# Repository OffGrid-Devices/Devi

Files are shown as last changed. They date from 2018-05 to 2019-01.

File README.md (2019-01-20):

# Devi
Arduino-based synthesizer 

[BOM](https://docs.google.com/spreadsheets/d/11OAxCDL9WJjP-PPryWPdmoXp5gGi14y3Fq-VU7GaQAA/edit?usp=sharing)

# Notes for further development

## Synth Variables

- fixedfreq (bool)
- coarse 
- detune 
- freqrange
- freqfixed
- depth 
- waveform
- attack
- decay 
- algorithm 

## Main Functions

- handleNoteOn
- handleNoteOff
- handleCC
- handleProgramChange
- sendNoteOn
- sendNoteOff
- sendCC
- sendProgramChange
- setMIDICH // runs @setup()
- setProgChangeBehavior // runs @setup()
- savePreset
- loadPreset
- initParams
- updateParams // hardware version of handleCC

## Control Modes

### 0 - Volumes & Mod Depths (RGB=OFF)
- knobs => depth 
- buttons do nothing (or may play individual oscillators)
- LED's show which oscillators are carriers

### 1 - Frequency (RGB=PURPLE)
- button + function => select if oscillator as fixed frequency or not (indicate with LED)
- knob => detune/freqfixed
- button + knob => coarse/freqrange

### 2 - Envelopes (RGB=BLUE)
- button + knob => attack
- knob => decay

### 3 - Waveform (RGB=WHITE)
- knob => waveform  
- buttons + knob6 => set several 
- function + knob => set all

### 4 - Load Preset (RGB=GREEN)
(leds indicate which preset is loaded using a binary representation)
### 5 - Save Preset (RGB=RED)

## FM Algorithms

### 0: six-voice polyphony, single oscillator
(1)|(2)|(3)|(4)|(5)|(6) 

### 1: three-voice polyphony, dual oscillator
(1)+(2)|(3)+(4)|(5)+(6)

### 2: two-voice polyphony, triple oscillator
(1)+(2)+(3)|(4)+(5)+(6)

### 3: three-voice polyphony, FM 2-operators
(2) | (4) | (6)
 |  |  |  |  |
(1) | (3) | (5)

### 4: two-voice polyphony, FM 3-operators
    (2) |     (6)
     |  |      | 
(1)+(3) | (4)+(5)

### 5: two-voice polyphony, FM 3-operators
  (3)   |   (6)
  / \   |   / \
(1)+(2) | (4)+(5)

### 6: two-voice polyphony, FM 3-operators
(2)+(3) | (5)+(6) 
  \ /   |   \ / 
  (1)   |   (4)

### 7: two-voice polyphony, FM 3-operators
(3) | (6)
 |  |  |
(2) | (5)
 |  |  |
(1) | (4)

### 8: monophonic, FM 6-operators
(3) (6)
 |   |
(2) (5)
 |   |
(1)+(4)

### 9: monophonic, FM 6-operators
  (3)     (6)
  / \     / \
(1)+(2) (4)+(5)

### 10: monophonic, FM 6-operators (needs experimentation...is it worth it have 6 stacked oscils when it is possible to change the waveform?)
    (6)             (6)
     |               |
    (5)             (5)
     |       OR      |
(2) (4)             (4)
 |   |               |
(1)+(3)             (3)
                     |
                    (2)
                     |
                    (1) 

### 11: super monophonic, six oscillators
(1)+(2)+(3)+(4)+(5)+(6)

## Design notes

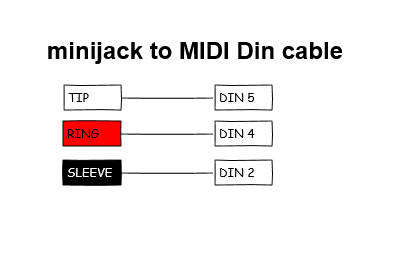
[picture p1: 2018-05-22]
schematics/MIDI minijack cables/MIDI to minijack.png

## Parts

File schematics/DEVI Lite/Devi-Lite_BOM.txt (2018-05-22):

Partlist exported from C:/Users/tiago/Documents/GitHub/OffGrid-Devices/Devi/schematics/DEVI Lite/Devi_Lite.sch at 22-05-2018 23:34

Qty Value               Device                  Package       Parts                                                                                                                                                                                                                   Description                     
7                       3RP/1610N               3RP/1610N     P1, P2, P3, P4, P5, P6, P8                                                                                                                                                                                              16mm Potentiometer one level    
1                       CK101X12                CK101X12      S1                                                                                                                                                                                                                      ROTARY SWITCH                   
7                       LED3MM                  LED3MM        LED1, LED2, LED3, LED4, LED5, LED6, LED7                                                                                                                                                                                LED                             
38                      PINHD-1X1CB             1X01-CLEANBIG JB1, JB2, JB3, JB4, JB5, JB6, JB7, JB8, JLED1, JLED2, JLED3, JLED4, JLED5, JLED6, JLED7, JLEDB, JLEDG, JLEDR, JP1, JP2, JP3, JP4, JP5, JP6, JP8-2, JP8-3, JS1, JS2, JS3, JS4, JS5, JS6, JS7, JS8, JS9, JS10, JS11, JS12 Pin header 1x1 for 0.1" spacing 
8                       SWITCH_PUSHBUTTONEVQ-PE TACT_PANA-EVQ SW1, SW2, SW3, SW4, SW5, SW6, SW7, SW8                                                                                                                                                                                  Buttons                         
2                       W237-103                W237-103      MIDI_IN, MIDI_OUT                                                                                                                                                                                                       WAGO SCREW CLAMP                
20  1K                  1KOHM-HORIZ-1/4W-5%     AXIAL-0.3     R1, R2, R3, R4, R5, R6, R7, R8, R9, R10, R11, R12, R13, R14, R15, R16, R17, R18, R19, R20                                                                                                                               1kO resistor                    
2   1M                  1KOHM-HORIZ-1/4W-5%     AXIAL-0.3     R21, R22                                                                                                                                                                                                                1kO resistor                    
1   200mA/100V/1V       DIODE-1N4148            DIODE-1N4148  D1                                                                                                                                                                                                                      Diode                           
3   220                 1KOHM-HORIZ-1/4W-5%     AXIAL-0.3     R24, R25, R27                                                                                                                                                                                                           1kO resistor                    
1   3K9                 1KOHM-HORIZ-1/4W-5%     AXIAL-0.3     R23                                                                                                                                                                                                                     1kO resistor                    
1   4.7nF               C-EU050-025X075         C050-025X075  C1                                                                                                                                                                                                                      CAPACITOR, European symbol      
1   4K7                 1KOHM-HORIZ-1/4W-5%     AXIAL-0.3     R26                                                                                                                                                                                                                     1kO resistor                    
1   6N138               6N138                   DIL08         OK1                                                                                                                                                                                                                     MOTOROLA OPTO COUPLER           
1   ARDUINO_MEGA_R3FULL ARDUINO_MEGA_R3FULL     ARDUINO_MEGA  B1                                                                                                                                                                                                                      Arduino Mega R3                 
1   CLEAR               LED-RGB-CCCLEAR         LED-RGB-THRU  RGB                                                                                                                                                                                                                     LED-RGB Common Cathode          
1   MONO_PLUG           MONO_PLUG               TWO_PADS      JA

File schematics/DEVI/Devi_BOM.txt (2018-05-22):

Partlist exported from C:/Users/tiago/Documents/GitHub/OffGrid-Devices/Devi/schematic/Devi_revB.sch at 21-05-2018 18:55

Qty Value               Device                  Package       Parts                                                                                                                                                                                                                                                                                                                           Description                     
8                       3RP/1610N               3RP/1610N     P1, P2, P3, P4, P5, P6, P7, P8                                                                                                                                                                                                                                                                                                  16mm Potentiometer one level    
2                       7SEG-CK                 7SEG-13       DLEFT, DRIGHT                                                                                                                                                                                                                                                                                                                   7-segment DISPLAY               
1                       CK101X12                CK101X12      S1                                                                                                                                                                                                                                                                                                                              ROTARY SWITCH                   
7                       LED3MM                  LED3MM        LED1, LED2, LED3, LED4, LED5, LED6, LED7                                                                                                                                                                                                                                                                                        LED                             
63                      PINHD-1X1CB             1X01-CLEANBIG 3V3, 5V, CD, CLK, CS, DI, DO, GND, JB1, JB2, JB3, JB4, JB5, JB6, JB7, JB8, JLED1, JLED2, JLED3, JLED4, JLED5, JLED6, JLED7, JLEDB, JLEDG, JLEDR, JP1, JP2, JP3, JP4, JP5, JP6, JP7, JP8-2, JP8-3, JS1, JS2, JS3, JS4, JS5, JS6, JS7, JS8, JS9, JS10, JS11, JS12, LA, LB, LC, LD, LE, LF, LG, LP, RA, RB, RC, RD, RE, RF, RG, RP Pin header 1x1 for 0.1" spacing 
8                       SWITCH_PUSHBUTTONEVQ-PE TACT_PANA-EVQ SW1, SW2, SW3, SW4, SW5, SW6, SW7, SW8                                                                                                                                                                                                                                                                                          Buttons                         
2                       W237-103                W237-103      MIDI_IN, MIDI_OUT                                                                                                                                                                                                                                                                                                               WAGO SCREW CLAMP                
20  1K                  1KOHM-HORIZ-1/4W-5%     AXIAL-0.3     R1, R2, R3, R4, R5, R6, R7, R8, R9, R10, R11, R12, R13, R14, R15, R16, R17, R18, R19, R20                                                                                                                                                                                                                                       1kO resistor                    
2   1M                  1KOHM-HORIZ-1/4W-5%     AXIAL-0.3     R21, R22                                                                                                                                                                                                                                                                                                                        1kO resistor                    
1   200mA/100V/1V       DIODE-1N4148            DIODE-1N4148  D1                                                                                                                                                                                                                                                                                                                              Diode                           
3   220                 1KOHM-HORIZ-1/4W-5%     AXIAL-0.3     R24, R25, R27                                                                                                                                                                                                                                                                                                                   1kO resistor                    
1   3K9                 1KOHM-HORIZ-1/4W-5%     AXIAL-0.3     R23                                                                                                                                                                                                                                                                                                                             1kO resistor                    
1   4.7nF               C-EU050-025X075         C050-025X075  C1                                                                                                                                                                                                                                                                                                                              CAPACITOR, European symbol      
1   4K7                 1KOHM-HORIZ-1/4W-5%     AXIAL-0.3     R26                                                                                                                                                                                                                                                                                                                             1kO resistor                    
1   6N138               6N138                   DIL08         OK1                                                                                                                                                                                                                                                                                                                             MOTOROLA OPTO COUPLER           
1   ARDUINO_MEGA_R3FULL ARDUINO_MEGA_R3FULL     ARDUINO_MEGA  B1                                                                                                                                                                                                                                                                                                                              Arduino Mega R3                 
1   CLEAR               LED-RGB-CCCLEAR         LED-RGB-THRU  RGB                                                                                                                                                                                                                                                                                                                             LED-RGB Common Cathode          
1   MONO_PLUG           MONO_PLUG               TWO_PADS      JA

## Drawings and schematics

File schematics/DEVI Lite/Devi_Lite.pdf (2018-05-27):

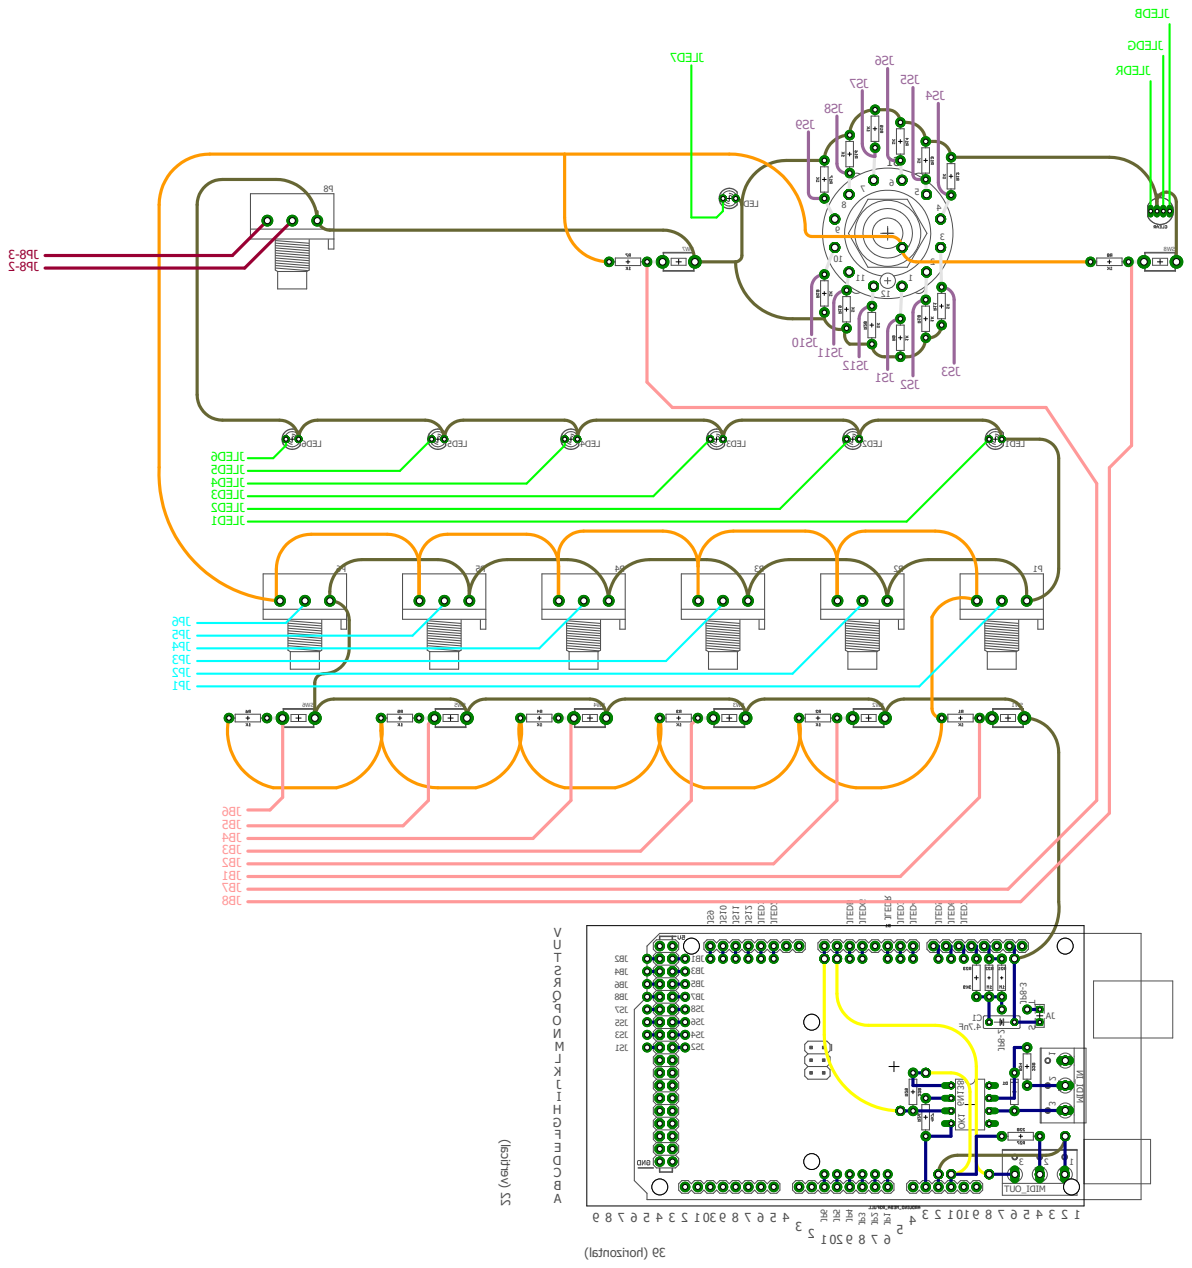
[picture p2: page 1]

Fn7. 4 6N138 1C AJ 2BJ 1BJ 4BJ 3BJ 6BJ 5BJ 8BJ 7BJ JLED1 JLED2 JLED3 JLED4 JLED5 JLED6 JLED7 JLEDB JLEDG JLEDR JP1 JP2 JP3JP4 JP5 JP6 1SJ JS10 JS11 JS12 2SJ 3SJ 4SJ 5SJ 6SJ 7SJ 8SJJS9 6DEL 5DEL 4DEL 3DEL 2DEL 1DEL 7DEL MIDI_IN TUO_I DI M OK1 6P 5P 4P 3P 2P 1P 8P 1S 6 WS 5 WS 4 WS 3 WS 2 WS 1 WS 7 WS 8 WS JP8-3 JP8-2 1 2 3 3 2 1 S T 1 2 34 5 6 7 8 901 11 21 1BJ 2BJ 3BJ 4BJ 5BJ 6BJ 7BJ 8BJ 1PJ 2PJ 3PJ 4PJ 5PJ 6PJ 1DELJ 2DELJ 3DELJ 4DELJ 5DELJ 6DELJ 7DELJ RDELJ GDELJ BDELJ 1SJ 2SJ 3SJ 4SJ 5SJ 6SJ 7SJ 8SJ 9SJ 01SJ11SJ21SJ 3- 8PJ 2- 8PJ )l at nozir oh( 93 22 (vertical) ABCDEFGHIJKLMNOPQRSTUV 3 2 1 01 9 8 7 6 5 4 3 2 1 4 5 1 02 9 8 7 6 2 3 9 8 7 6 5 4 3 2 1 03 9 8 7 6 5 4

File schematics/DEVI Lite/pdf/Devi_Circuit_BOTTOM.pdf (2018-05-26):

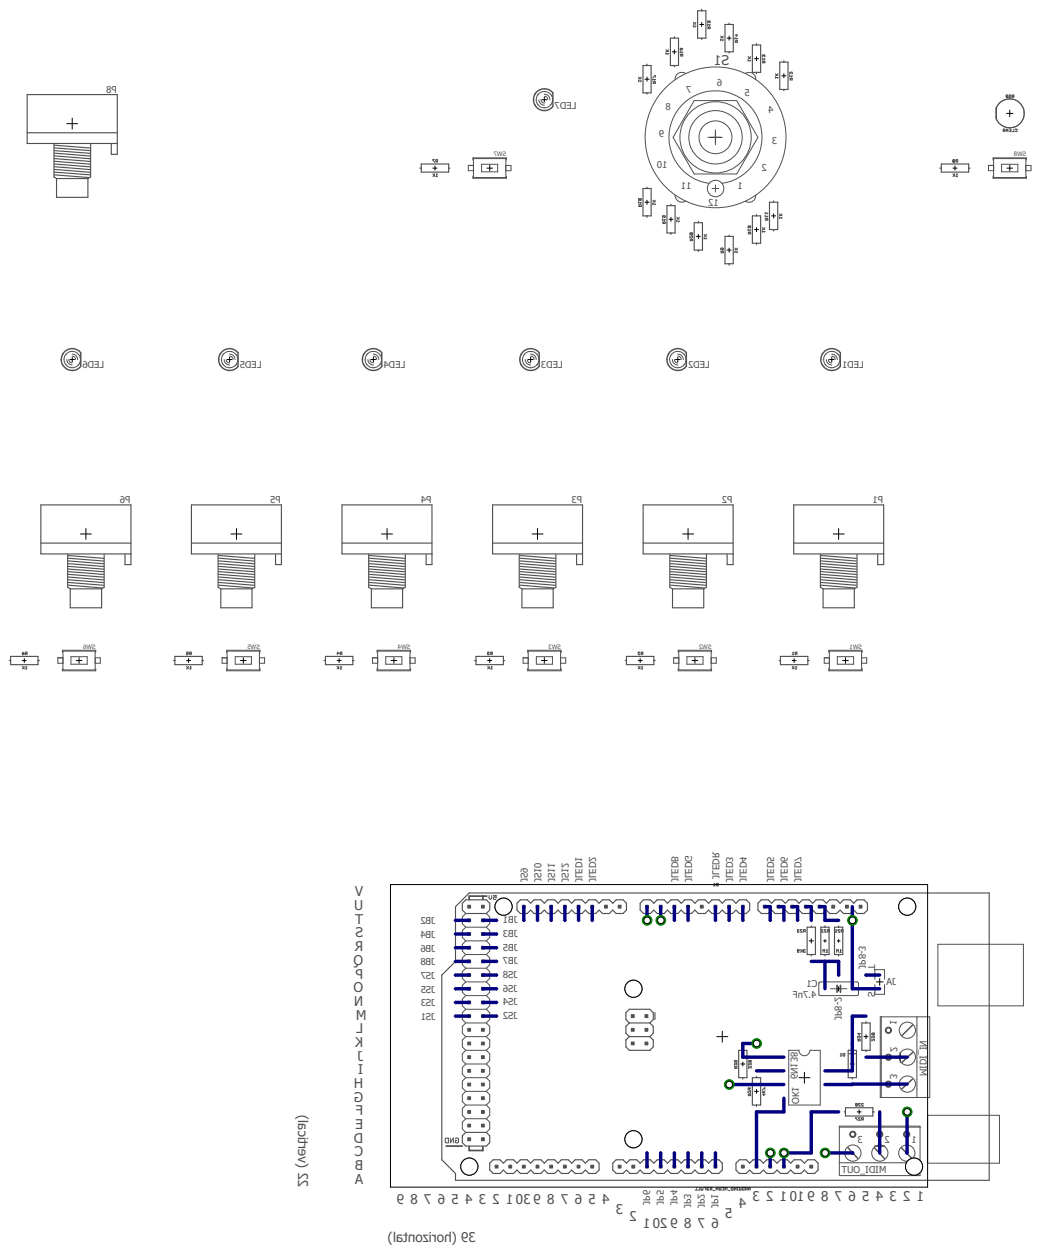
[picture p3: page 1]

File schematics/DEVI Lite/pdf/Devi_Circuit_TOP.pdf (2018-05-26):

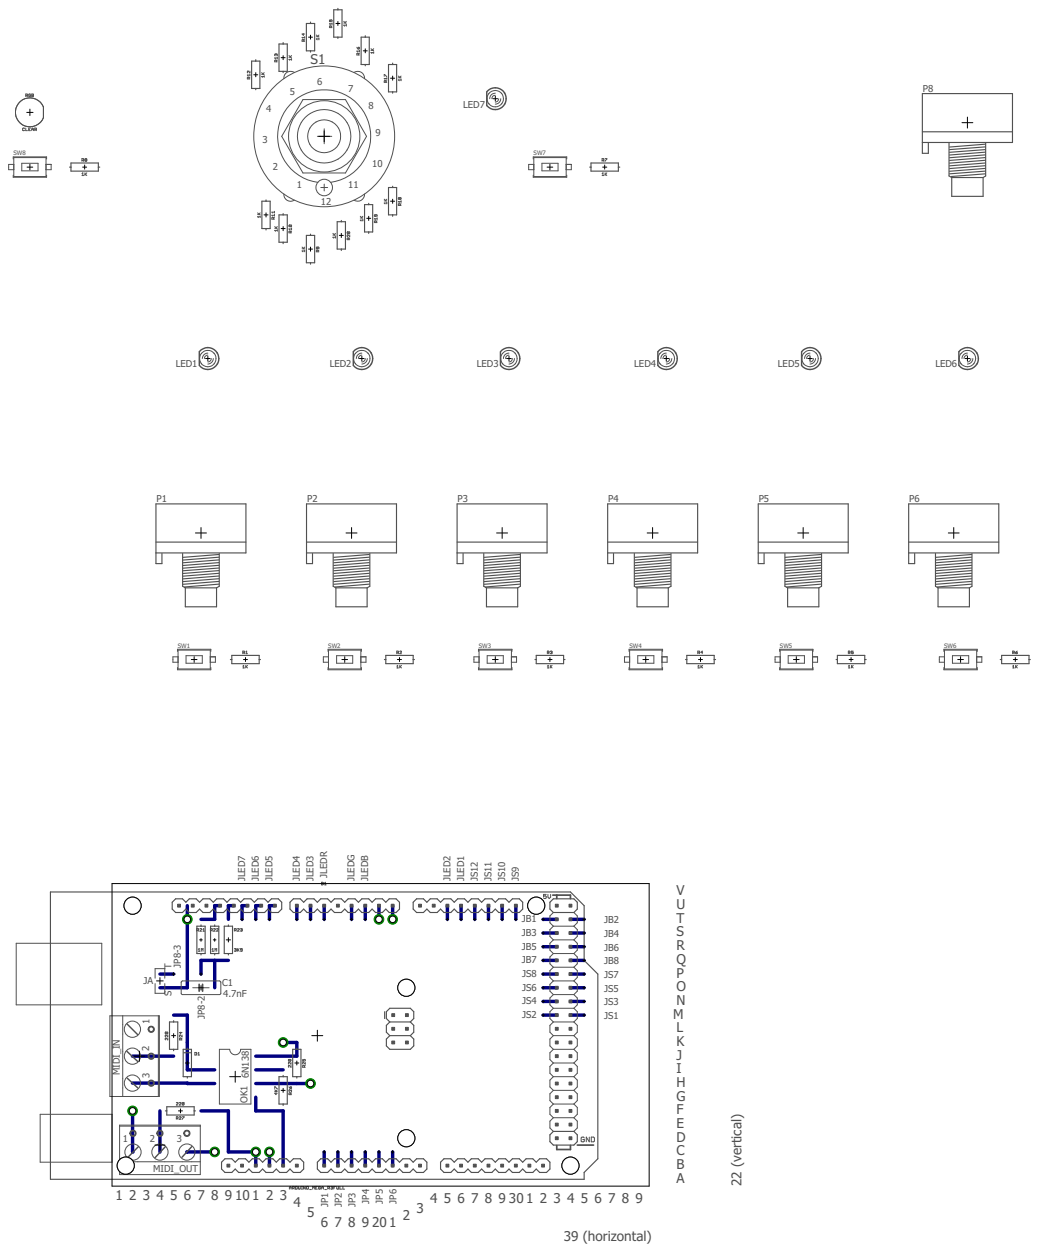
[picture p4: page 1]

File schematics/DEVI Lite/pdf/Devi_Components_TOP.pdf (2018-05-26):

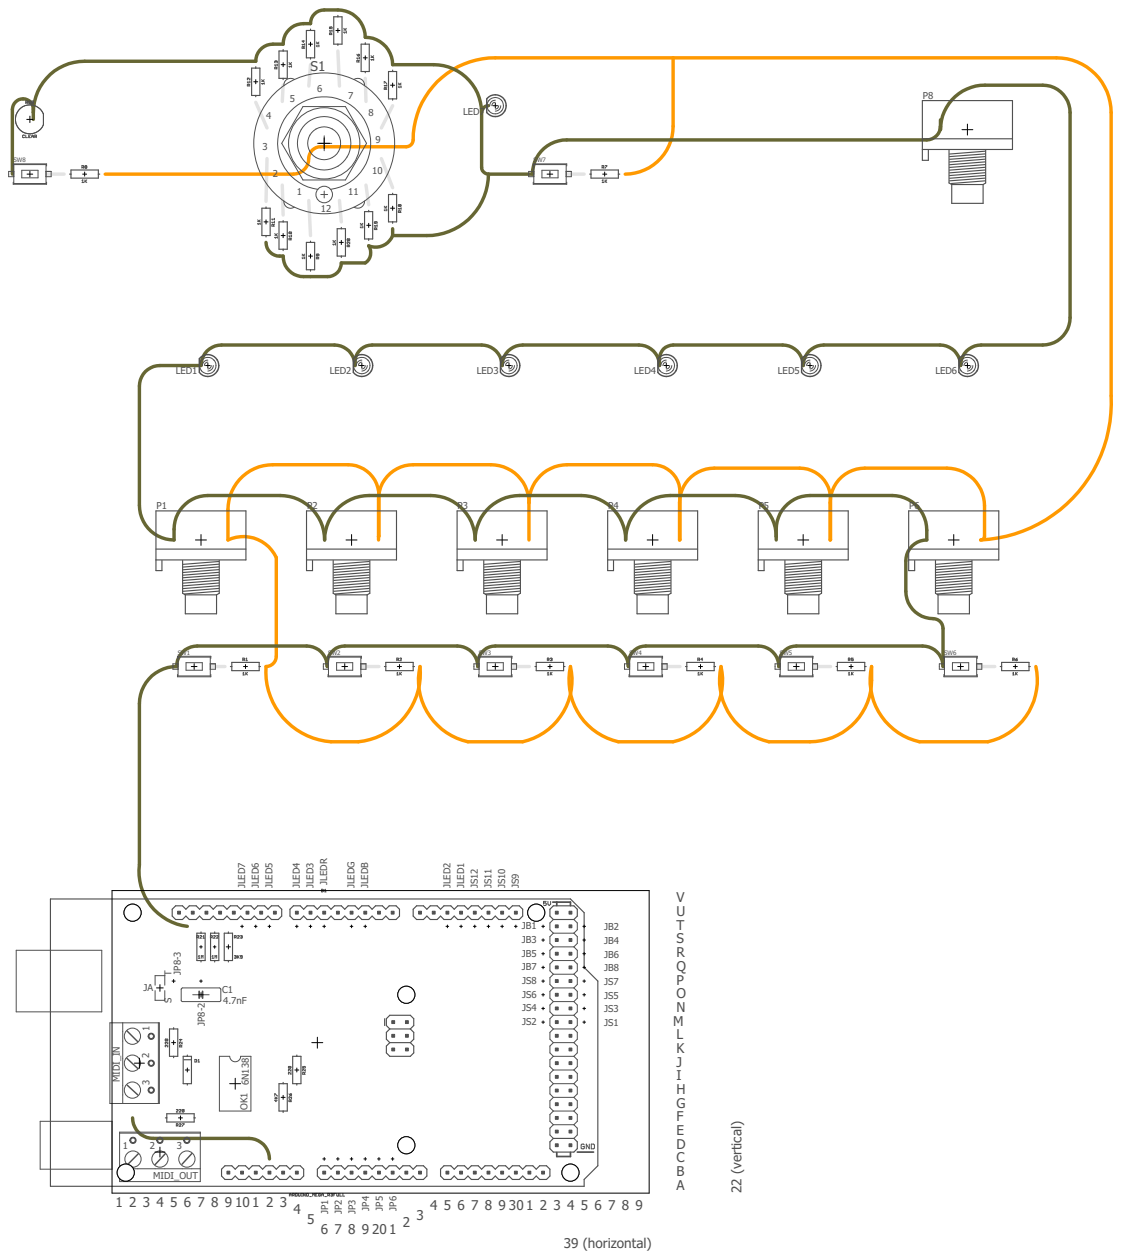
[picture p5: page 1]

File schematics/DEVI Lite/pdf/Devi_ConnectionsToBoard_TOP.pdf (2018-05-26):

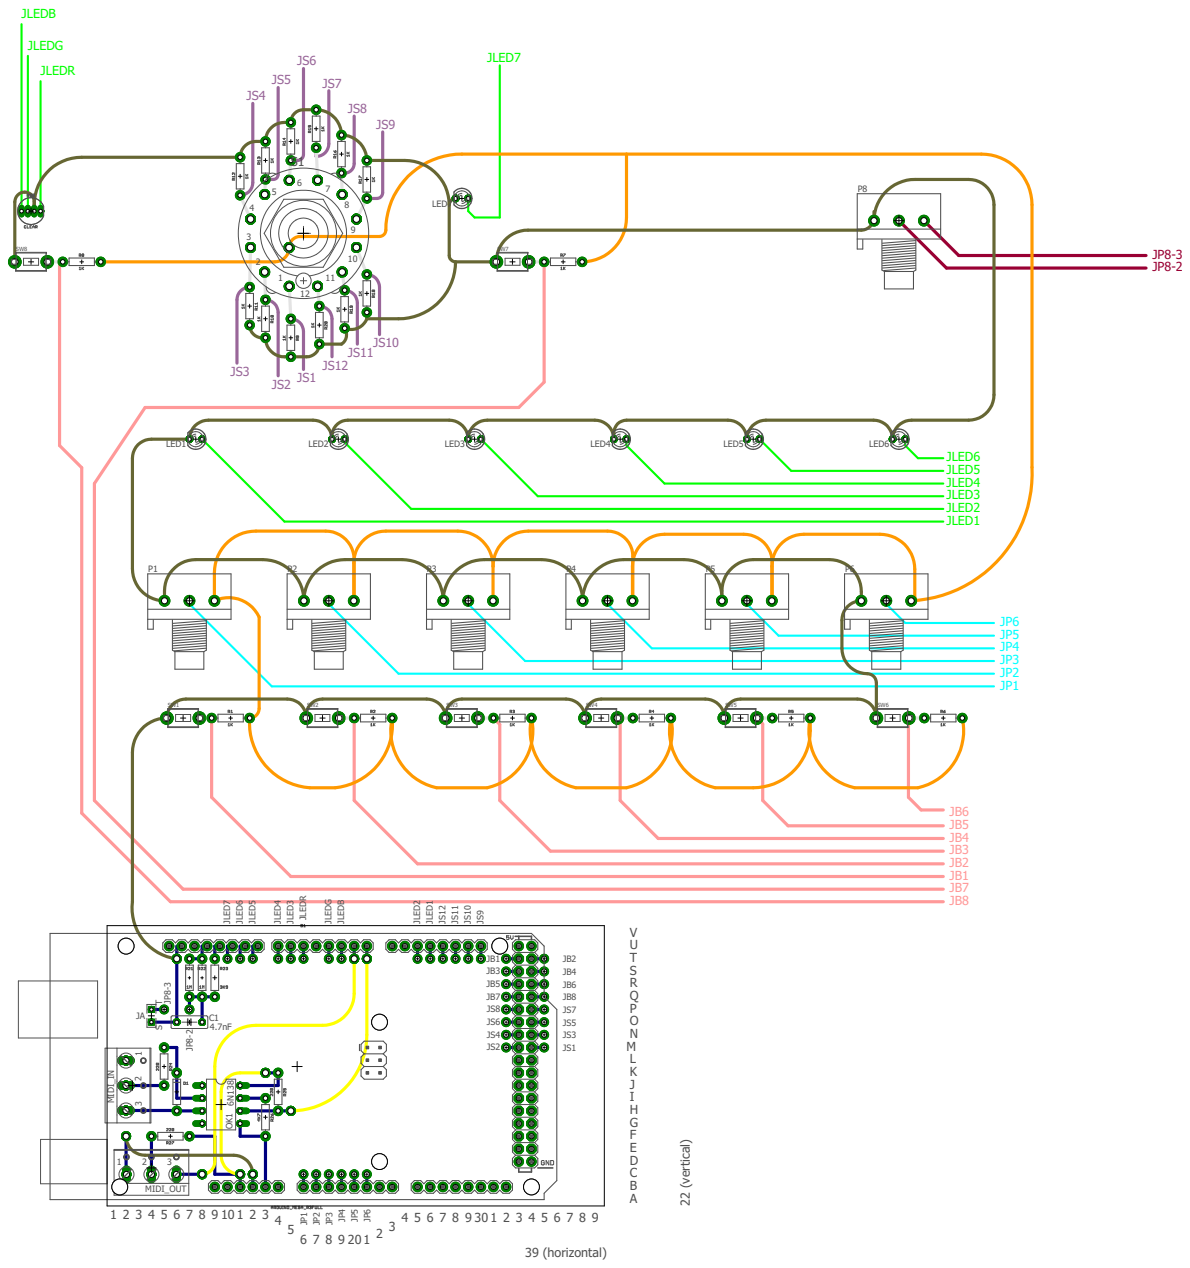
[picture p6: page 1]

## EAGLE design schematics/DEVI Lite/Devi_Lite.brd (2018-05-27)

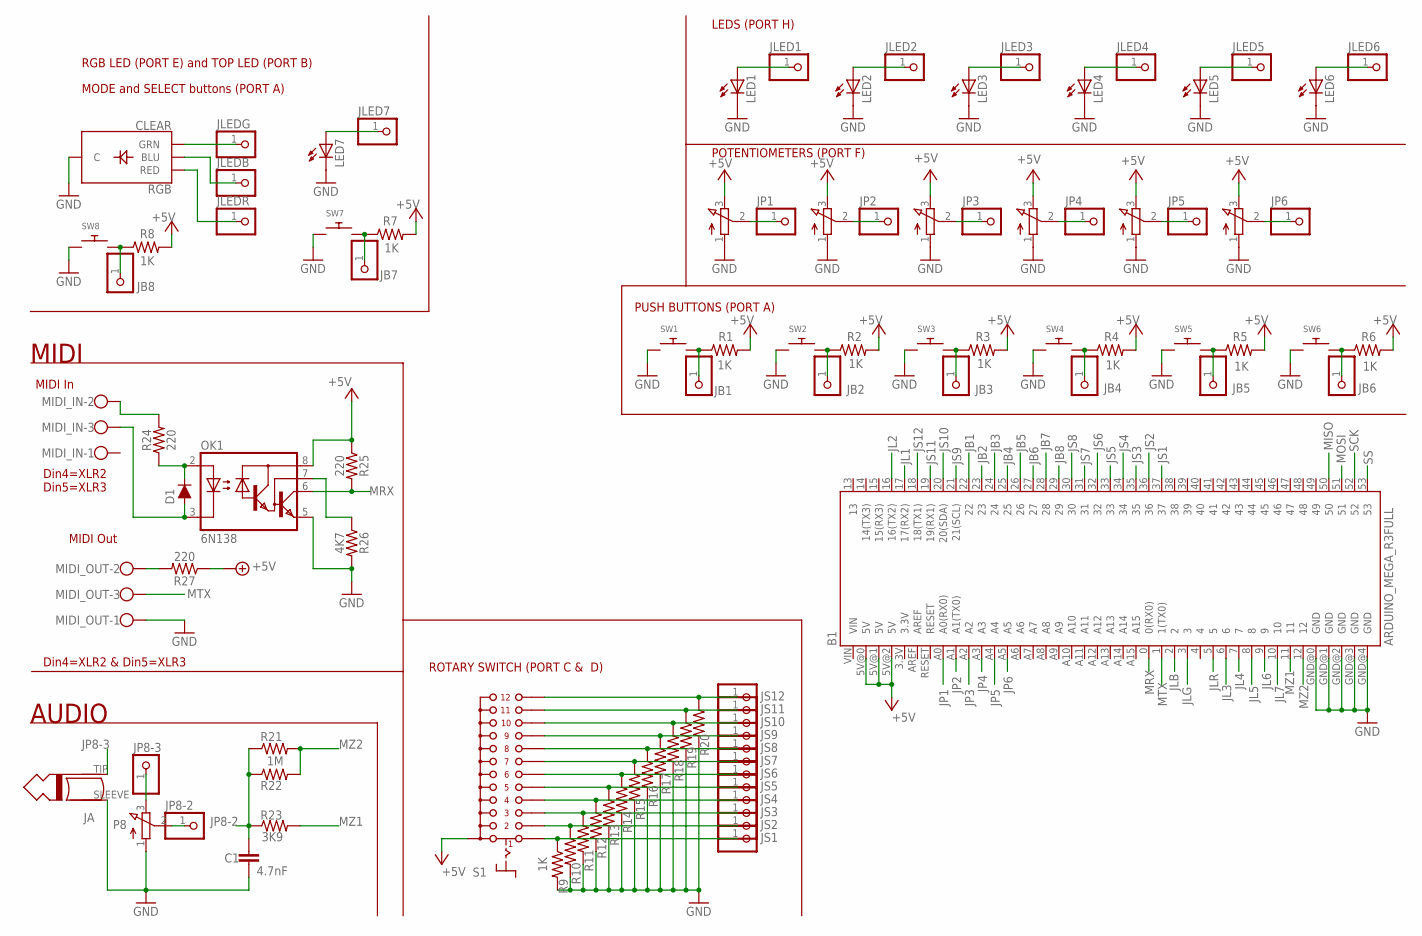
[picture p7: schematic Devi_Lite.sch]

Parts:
B1: ARDUINO_MEGA_R3FULL; ARDUINO_MEGA
C1: 4.7nF; C050-025X075
D1: 200mA/100V/1V; DIODE-1N4148
JA: MONO_PLUG; TWO_PADS
JB1, JB2, JB3, JB4, JB5, JB6, JB7, JB8: PINHD-1X1CB; 1X01-CLEANBIG
JLED1, JLED2, JLED3, JLED4, JLED5, JLED6, JLED7: PINHD-1X1CB; 1X01-CLEANBIG
JLEDB: PINHD-1X1CB; 1X01-CLEANBIG
JLEDG: PINHD-1X1CB; 1X01-CLEANBIG
JLEDR: PINHD-1X1CB; 1X01-CLEANBIG
JP1, JP2, JP3, JP4, JP5, JP6, JP8-2, JP8-3: PINHD-1X1CB; 1X01-CLEANBIG
JS1, JS2, JS3, JS4, JS5, JS6, JS7, JS8, JS9, JS10, JS11, JS12: PINHD-1X1CB; 1X01-CLEANBIG
LED1, LED2, LED3, LED4, LED5, LED6, LED7: LED3MM
MIDI_IN: W237-103
MIDI_OUT: W237-103
OK1: 6N138; DIL08
P1, P2, P3, P4, P5, P6, P8: 3RP/1610N
R1, R2, R3, R4, R5, R6, R7, R8, R9, R10, R11, R12, R13, R14, R15, R16, R17, R18, R19, R20: 1K; AXIAL-0.3
R21, R22: 1M; AXIAL-0.3
R23: 3K9; AXIAL-0.3
R24, R25, R27: 220; AXIAL-0.3
R26: 4K7; AXIAL-0.3
RGB: CLEAR; LED-RGB-THRU
S1: CK101X12
SW1, SW2, SW3, SW4, SW5, SW6, SW7, SW8: SWITCH_PUSHBUTTONEVQ-PE; TACT_PANA-EVQ

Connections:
+5V: B1.5V@0 (5V), B1.5V@1 (5V), B1.5V@2 (5V), OK1.8 (VCC), P1.3 (E), P2.3 (E), P3.3 (E), P4.3 (E), P5.3 (E), P6.3 (E), R1.P$2 (2), R2.P$2 (2), R3.P$2 (2), R4.P$2 (2), R5.P$2 (2), R6.P$2 (2), R7.P$2 (2), R8.P$2 (2), R25.P$1 (1), R27.P$1 (1), S1.A
GND: B1.GND@0 (GND), B1.GND@1 (GND), B1.GND@2 (GND), B1.GND@3 (GND), B1.GND@4 (GND), C1.2, JA.SLEEVE, LED1.K (C), LED2.K (C), LED3.K (C), LED4.K (C), LED5.K (C), LED6.K (C), LED7.K (C), MIDI_OUT.1, OK1.5 (GND), P1.1 (A), P2.1 (A), P3.1 (A), P4.1 (A), P5.1 (A), P6.1 (A), P8.1 (A), R9.P$2 (2), R10.P$2 (2), R11.P$2 (2), R12.P$2 (2), R13.P$2 (2), R14.P$2 (2), R15.P$2 (2), R16.P$2 (2), R17.P$2 (2), R18.P$2 (2), R19.P$2 (2), R20.P$2 (2), R26.P$2 (2), RGB.2 (C), SW1.P$1, SW2.P$1, SW3.P$1, SW4.P$1, SW5.P$1, SW6.P$1, SW7.P$1, SW8.P$1
JB1: B1.22, JB1.1, R1.P$1 (1), SW1.P$2
JB2: B1.23, JB2.1, R2.P$1 (1), SW2.P$2
JB3: B1.24, JB3.1, R3.P$1 (1), SW3.P$2
JB4: B1.25, JB4.1, R4.P$1 (1), SW4.P$2
JB5: B1.26, JB5.1, R5.P$1 (1), SW5.P$2
JB6: B1.27, JB6.1, R6.P$1 (1), SW6.P$2
JB7: B1.28, JB7.1, R7.P$1 (1), SW7.P$2
JB8: B1.29, JB8.1, R8.P$1 (1), SW8.P$2
JL1: B1.17 (17(RX2)), JLED1.1, LED1.A
JL2: B1.16 (16(TX2)), JLED2.1, LED2.A
JL3: B1.6, JLED3.1, LED3.A
JL4: B1.7, JLED4.1, LED4.A
JL5: B1.8, JLED5.1, LED5.A
JL6: B1.9, JLED6.1, LED6.A
JL7: B1.10, JLED7.1, LED7.A
JLB: B1.2, JLEDB.1, RGB.4 (BLU)
JLG: B1.3, JLEDG.1, RGB.3 (GRN)
JLR: B1.5, JLEDR.1, RGB.1 (RED)
JP1: B1.A0 (A0(RX0)), JP1.1, P1.2 (S)
JP2: B1.A1 (A1(TX0)), JP2.1, P2.2 (S)
JP3: B1.A2, JP3.1, P3.2 (S)
JP4: B1.A3, JP4.1, P4.2 (S)
JP5: B1.A4, JP5.1, P5.2 (S)
JP6: B1.A5, JP6.1, P6.2 (S)
JP8-2: C1.1, JP8-2.1, P8.2 (S), R21.P$1 (1), R22.P$1 (1), R23.P$1 (1)
JP8-3: JA.TIP, JP8-3.1, P8.3 (E)
JS1: B1.37, JS1.1, R9.P$1 (1), S1.1
JS2: B1.36, JS2.1, R10.P$1 (1), S1.2
JS3: B1.35, JS3.1, R11.P$1 (1), S1.3
JS4: B1.34, JS4.1, R12.P$1 (1), S1.4
JS5: B1.33, JS5.1, R13.P$1 (1), S1.5
JS6: B1.32, JS6.1, R14.P$1 (1), S1.6
JS7: B1.31, JS7.1, R15.P$1 (1), S1.7
JS8: B1.30, JS8.1, R16.P$1 (1), S1.8
JS9: B1.21 (21(SCL)), JS9.1, R17.P$1 (1), S1.9
JS10: B1.20 (20(SDA)), JS10.1, R18.P$1 (1), S1.10
JS11: B1.19 (19(RX1)), JS11.1, R19.P$1 (1), S1.11
JS12: B1.18 (18(TX1)), JS12.1, R20.P$1 (1), S1.12
MISO: B1.50
MOSI: B1.51
MRX: B1.0 (0(RX0)), OK1.6 (VO), R25.P$2 (2)
MTX: B1.1 (1(TX0)), MIDI_OUT.3
MZ1: B1.11, R23.P$2 (2)
MZ2: B1.12, R21.P$2 (2), R22.P$2 (2)
unnamed: D1.A, MIDI_IN.3, OK1.3 (C)
unnamed: D1.C, OK1.2 (A), R24.P$1 (1)
unnamed: MIDI_IN.2, R24.P$2 (2)
unnamed: OK1.7 (VB), R26.P$1 (1)
unnamed: MIDI_OUT.2, R27.P$2 (2)
SCK: B1.52
SS: B1.53

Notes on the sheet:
POTENTIOMETERS (PORT F)
PUSH BUTTONS (PORT A)
RGB LED (PORT E) and TOP LED (PORT B)
LEDS (PORT H)
MODE and SELECT buttons (PORT A)
MIDI
MIDI In
Din4=XLR2 Din5=XLR3
MIDI Out
Din4=XLR2 & Din5=XLR3
ROTARY SWITCH (PORT C & D)
AUDIO

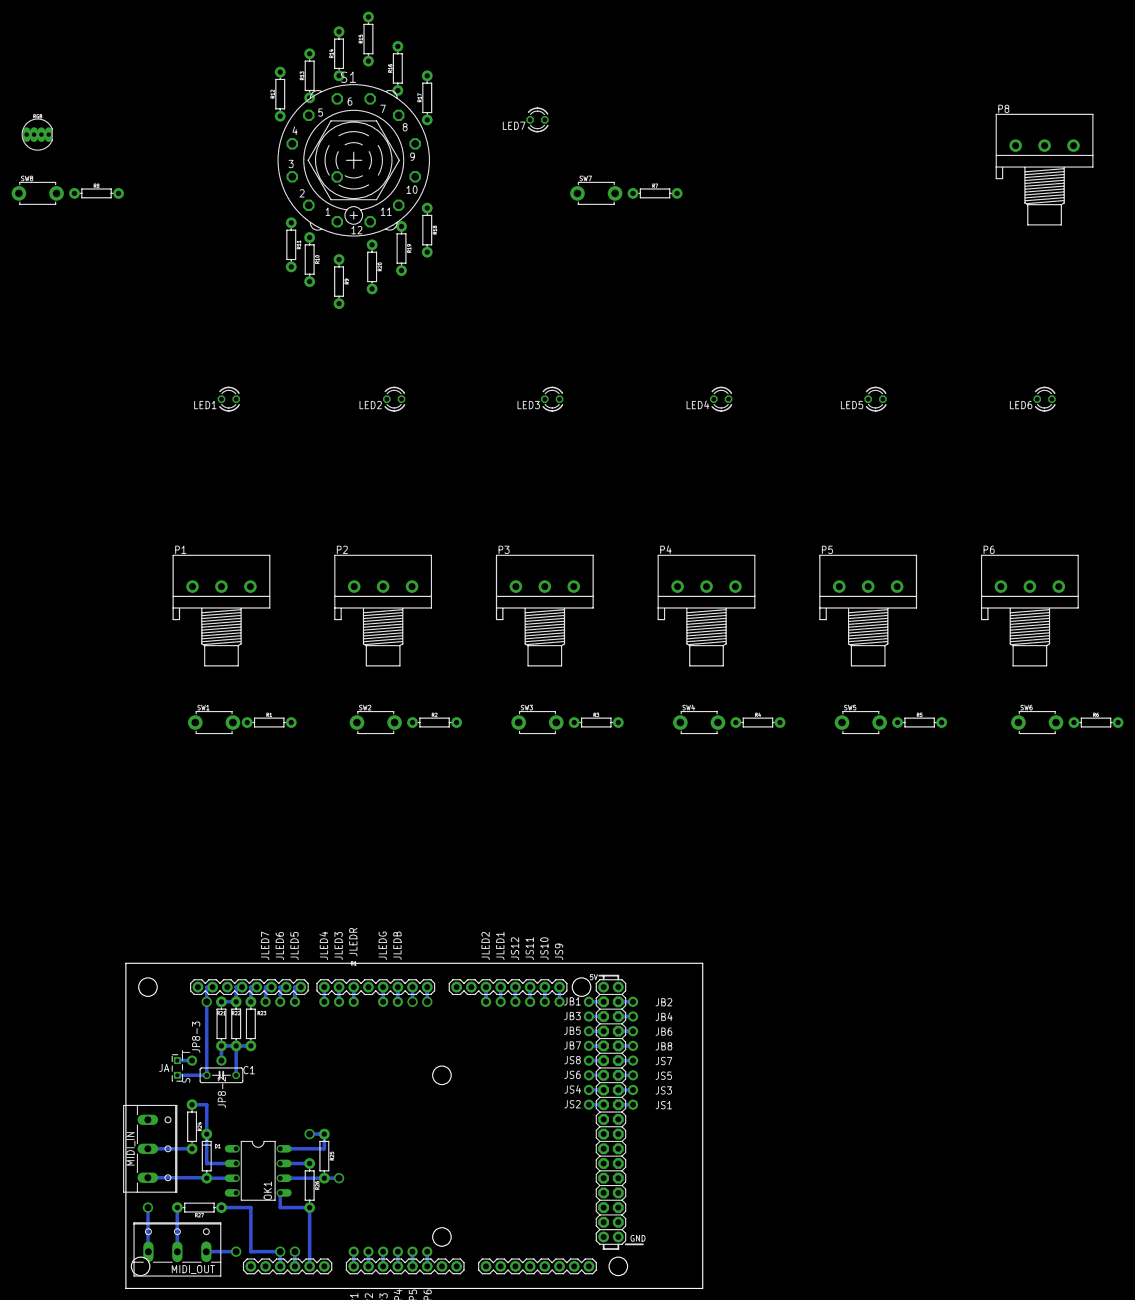
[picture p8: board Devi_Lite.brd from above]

Board: 16 copper layers, 99.7 x 56.2 mm, 96 parts (0 on the bottom side), 49 nets.

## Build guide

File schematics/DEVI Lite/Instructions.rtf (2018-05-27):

Step #1:
Before breaking the board look at step #2, then break the veroboard using X x Y holes, like so:
[picture]

Step #2:
Mark the veroboard so that you can easily connect all the wires later.
[picture]

Step #3:
cut the headers and solder them

Step#4:
place components for the audio circuit and solder

Step#5
place MIDI circuit components and solder

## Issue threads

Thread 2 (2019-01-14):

Rotary switch problem

p1nh0, 2019-01-14:
When in position "6" two input ports get HIGH instead of just one.
See problem using "../hardware test/ROT_test.ino"

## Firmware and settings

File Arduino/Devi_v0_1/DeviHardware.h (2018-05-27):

/*
 * DeviHardware.h
 *
 * Created: 25-05-2018 21:33:28
 *  Author: tiago
 */ 


#ifndef DEVIHARDWARE_H_
#define DEVIHARDWARE_H_

//HARDWARE PIN CONFIGURATION 

// Port A - Buttons
#define PINBUT1 22 // PA0
#define PINBUT2 23 // PA1
#define PINBUT3 24 // PA2
#define PINBUT4 25 // PA3
#define PINBUT5 26 // PA4
#define PINBUT6 27 // PA5
#define PINBUT7 28 // PA6
#define PINBUT8 29 // PA7
// Port F - Potentiometers
#define PINPOT1 A0 // PF0
#define PINPOT2 A1 // PF1
#define PINPOT3 A2 // PF2
#define PINPOT4 A3 // PF3
#define PINPOT5 A4 // PF4
#define PINPOT6 A5 // PF5
// PORT H - Leds
#define PINLED1 17 // PH0
#define PINLED2 16 // PH1
#define PINLED3 6 // PH3
#define PINLED4 7 // PH4
#define PINLED5 8 // PH5
#define PINLED6 9 // PH6
// PORT B - Led#7
#define PINLED7 10 // PB4
// PORT E - Led RGB
#define PINRED 5 // PE3
#define PINGREEN 3 // PE4
#define PINBLUE 2 // PE5
// PORT C & D - Rotary switch
#define PINROT1 37 // PC0
#define PINROT2 36 // PC1
#define PINROT3 35 // PC2
#define PINROT4 34 // PC3
#define PINROT5 33 // PC4
#define PINROT6 32 // PC5
#define PINROT7 31 // PC6
#define PINROT8 30 // PC7
#define PINROT9 21 // PD0
#define PINROT10 20 // PD1
#define PINROT11 19 // PD2
#define PINROT12 18 // PD3



#endif /* DEVIHARDWARE_H_ */

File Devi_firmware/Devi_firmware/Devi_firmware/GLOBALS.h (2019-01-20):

/*
 * GLOBALS.h
 *
 * Created: 15-04-2018 11:55:49
 *  Author: tiago
 */ 


#ifndef GLOBALS_H_
#define GLOBALS_H_

// COMPILER
#define OPTIMIZATION "O2"
#pragma GCC push_options
#pragma GCC optimize (OPTIMIZATION)

// INCLUDES

// MACROS
#define bit_get(p,m) ((p) & (m))
#define bit_set(p,m) ((p) |= (m))
#define bit_clear(p,m) ((p) &= ~(m))
#define BIT(x)(0x01 << (x))
#ifndef cbi
#define cbi(sfr, bit) (_SFR_BYTE(sfr) &= ~_BV(bit))
#endif
#ifndef sbi
#define sbi(sfr, bit) (_SFR_BYTE(sfr) |= _BV(bit))
#endif

// DEFINITIONS
#define NUMVOICES 6 // max=8 with very simple code
#define MINPITCH 24
#define MAXFREQ 12000 // filter maximum frequency



// STORED VARIABLES (struct size = 128Bytes x 12 presets = 1536Bytes) ArduinoMega EEPROM = 4096Bytes
struct Preset{ 
//////////////////////////////////////////////////////////////////////////
// SEQUENCER VARIABLES //////////////////////////////////////////////////
////////////////////////////////////////////////////////////////////////
boolean mute[6] = {true, true, true, true, true, true}; // step mute
uint8_t steps = 6; // selected number of steps
uint8_t stepMode = 0; // up, down, up&down, palindrome, random step, random step & pitch

//////////////////////////////////////////////////////////////////////////
// SYNTH VOICE VARIABLES ////////////////////////////////////////////////
////////////////////////////////////////////////////////////////////////
// Carrier oscillator
uint8_t pitch[6] = {36, 39, 43, 46, 48, 29}; // carrier pitch
uint8_t wave[8]; // carrier waveform: 0-sin, 1-tri, 2-rampup, 3-rampdown, 4-square, 5-noise
// Modulator oscillator
uint8_t modpitch[6] = {36, 39, 43, 46, 48, 29}; // modulator pitch	
uint8_t modwave[8]; // carrier waveform: 0-sin, 1-tri, 2-rampup, 3-rampdown, 4-square, 5-noise
// Modulation parameters
int8_t modamount[6]; // modulation amount
int8_t envamount[6]; // envelope to modulation amount 
// Envelope 
unsigned int att[6] = {25, 25, 25, 25, 25, 25}; 
unsigned int dcy[6] = {150, 150, 150, 150, 150, 150}; 
// FX
uint8_t fxtype[6]; // 0-OFF, 1-<<, 2->>, 3-&, 4-|, 5-^
uint8_t fxamount[6]; // fx parameter/amount
// FILTER 
uint8_t filtertype[6];// 0-LP, 1-BAND, 1-HP, 2-NOTCH
uint16_t filterfreq[6] = {12000, 12000, 12000, 12000, 12000, 12000, }; // filter cutoff frequency
uint8_t filterres[6] = {127, 127, 127, 127, 127, 127}; // filter resonance
int8_t filtermod[6]; // LFO to filter modulation amount	
// LFO
uint16_t lfofreq[6] = {4, 4, 4, 4, 4, 4}; // lfo frequency
uint8_t lfowave[8]; // lfo waveform: 0-sin, 1-tri, 2-rampup, 3-rampdown, 4-square, 5-noise 
};



// NON-STORED VARIABLES
uint8_t rotary, _rotary; // current and previous rotary switch value 
uint8_t ledPinSequence[6] = {17, 16, 6, 7, 8, 9};

// TABLES 
float detuneTable[128] = {-0.5, -0.49, -0.48, -0.48, -0.47, -0.46, -0.45, -0.45, -0.44, -0.43, -0.42, -0.41, -0.41, -0.4, -0.39, -0.38, -0.38, -0.37, -0.36, -0.35, -0.34, -0.34, -0.33, -0.32, -0.31, -0.3, -0.3, -0.29, -0.28, -0.27, -0.27, -0.26, -0.25, -0.24, -0.23, -0.23, -0.22, -0.21, -0.2, -0.2, -0.19, -0.18, -0.17, -0.16, -0.16, -0.15, -0.14, -0.13, -0.13, -0.12, -0.11, -0.1, -0.09, -0.09, -0.08, -0.07, -0.06, -0.05, -0.05, -0.04, -0.03, -0.02, -0.02, -0.01, 0., 0.01, 0.02, 0.02, 0.03, 0.04, 0.05, 0.05, 0.06, 0.07, 0.08, 0.09, 0.09, 0.1, 0.11, 0.12, 0.13, 0.13, 0.14, 0.15, 0.16, 0.16, 0.17, 0.18, 0.19, 0.2, 0.2, 0.21, 0.22, 0.23, 0.23, 0.24, 0.25, 0.26, 0.27, 0.27, 0.28, 0.29, 0.3, 0.3, 0.31, 0.32, 0.33, 0.34, 0.34, 0.35, 0.36, 0.37, 0.38, 0.38, 0.39, 0.4, 0.41, 0.41, 0.42, 0.43, 0.44, 0.45, 0.45, 0.46, 0.47, 0.48, 0.48, 0.49,};
Q7n0 coarseTable[8] = {-36, -24, -12, 0, 12, 24, 36, 48};

	
#pragma GCC pop_options

#endif /* GLOBALS_H_ */

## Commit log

2018-04-17 first running example
    implemented:
    - MODE button+RGB led
    - simple sequencer
2018-04-18 added pot control
    - basic potentiomer read to pitch sequence
2018-04-21 fixed led's not fully lit
    was forgetting to declare pins as outputs
2018-04-22 added led blinking bpm seq controls
    now stops and starts metronome according to BUTTON and MODE
2018-04-22 implemented sequencer modes
    up, down, up&down, palindrome, random step, random step & pitch
2018-05-22 Devi schematics
    [Devi.brd, Devi.sch]
2018-05-22 Devi_Lite schematics
    [Devi_Lite.brd, Devi_Lite.sch]
2018-05-22 added veroboard size
    [Devi_Lite.brd]
2018-05-22 updated pin numbers
2018-05-22 add Devi-Lite BOM
2018-05-22 schematic for MIDI Din to minijack cable
2018-05-25 reading buttons via PIN
2018-05-25 implemented rotary switch read
2018-05-25 Implemented Mode button+led
2018-05-25 Step mutes working
    although there is stil a minor glitch in the muted led's (no biggie for
    now)
2018-05-25 added rotary switch read function
2018-05-26 implemented editorA: carrier pitch and waveform
2018-05-26 uploaded Devi-Lite pdf schematics
2018-05-27 uploaded arduino-formatted code
2019-01-19 added pitch control

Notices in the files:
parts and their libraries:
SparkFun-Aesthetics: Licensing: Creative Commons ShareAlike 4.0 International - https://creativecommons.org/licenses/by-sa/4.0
